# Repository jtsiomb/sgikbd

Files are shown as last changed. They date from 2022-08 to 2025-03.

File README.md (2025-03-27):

SGI - PS/2 keyboard and mouse converter
=======================================

About
-----
This project is a converter for connecting PS/2 keyboards and mice to old
Silicon Graphics computers which had a proprietary keyboard/mouse interface. It
should work on every non-PS/2 SGI computer with mini-DIN6, DB9 and DB15
keyboard/mouse connectors, such as:

  - Iris 4D series
  - Onyx
  - Indigo

This converter is not necessary, and will not work, for any later SGI machines,
like the indy, O2, indigo2, Octane, and so on, because they use PS/2 keyboards
and mice directly.

It's based on an AVR atmega328pb microcontroller, which reads the PS/2
keyboard and mouse ports, and translates scancodes and events to the protocol
and electrical signalling used by the SGI computers. For details on the
SGI signalling and protocols, see the copy of the keyboard and mouse manpages
from the section 7 of the IRIX manual, under `doc/`.

Directory structure:

  - `hw` - hardware: kicad files and pdf schematics.
  - `fw` - firmware for the AVR microcontroller.
  - `case` - 3D printable enclosure for the sgikbd board.
  - `doc` - relevant documentation.

This repository only contains source files. For schematics in PDF format,
zipped gerbers for PCB manufacturing, and human-readable bill of materials, as
well as detailed build instructions, visit the project website:
http://nuclear.mutantstargoat.com/hw/sgikbd

Alternatively download the latest release archive from:
https://github.com/jtsiomb/sgikbd/releases

The firmware is based on my previous
[a500kbd](https://github.com/jtsiomb/a500kbd) project, so if you see any
leftover references to the Amiga anywhere don't be confused.

Note: rev3 of the sgikbd board uses a jumper (J2) to select the negative supply
voltage source. Make sure to **install a jumper there, do not leave it open**.
In most cases the jumper should be placed in the "default" position, but for
some workstations (notably the R3000 indigo) which don't provide a negative
supply on the keyb/mouse port, you might have to move it to the "R3k indigo"
position instead.

For previous revisions of sgikbd, see
[these instructions](http://nuclear.mutantstargoat.com/hw/sgikbd/indigo_r3000_hack.html)
on how to hack it to work with the R3000 indigo.

License
-------
Copyright (C) 2017-2025 John Tsiombikas <nuclear@mutantstargoat.com>

You are free to use, reproduce, modify, and redistribute any part of this
project, provided you make any derivative work you release, freely available
under the same terms.

Both hardware designs, and software parts of this project, are released under
the terms of the GNU General Public License v3, or at your option any later
version published by the Free Software Foundation. See `LICENSE` for details.

To comply with the license, when releasing derivative hardware designs, you must
provide the full EDA project files, and of course firmware/software source code.
Releasing only images of schematics, gerbers, and firmware binaries is *not*
sufficient for compliance.

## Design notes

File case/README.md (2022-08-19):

3D printable case for the sgikbd board
======================================

shot

This case was designed with OpenSCAD. In release archives, this directory
contains STL files exported from OpenSCAD, otherwise if you got this from the
git repository, you will only find the OpenSCAD source file, which you will have
to export yourself. To do so, simply load the `sgikbd.scad` file in OpenSCAD,
press F6 to generate the final geometry for the model, and then press F7 to
export to STL format.

File list
---------
  - `sgikbd.scad`: source file, open it with OpenSCAD to export STL files.
  - `sgikbd-bot.stl`: STL file containing the bottom part of the case in the
    default configuration.
  - `sgikbd-top.stl`: STL file containing the top part of the case in the default
    configuration.
  - `sgikbd-top-allports.stl`: STL file containing the top part of the case, with
    all SGI ports open (no break-away panels).

Options
-------
If you open the source file in openscad and export to STL manually, you can
tweak a number of options about the case. You will find these options at the top
of the file. The default configuration includes break-away panels for all SGI
ports, which you'll have to remove for every connector you have actually
populated on the board. However you have the option to either make any of the
ports completely solid, if you're sure you're not going to populate that
connector in the future, or leave any of the ports completely open.

  - `breaktabs`: set to false to leave ports open, instead of having the default
    break-away panel.
  - `no_db15`: set to true to completely block the DB15 port with solid wall.
  - `no_db9`: set to true to completely block the DB9 port (IRIS 4D series) with
    solid wall.
  - `no-minidin`: set to true to completely block the MiniDIN port (Indigo/Onyx)
    with solid wall.
  - `have_top`: set to false to omit the top part of the case.
  - `have_bottom`: set to false to omit the bottom part of the case.

License
-------
Creator: John Tsiombikas <nuclear@mutantstargoat.com>

This case design is public domain, feel free to copy, modify, and use, as you
will, without restriction.

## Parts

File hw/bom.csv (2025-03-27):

Description | Count | Designator | Footprint | Mouser Part #
22pF capacitor | 2 | C1, C2 | 0805 | 187-CL21C220JBANNNC
0.1uF capacitor | 4 | C3, C6, C7, C9 | 0805 | 187-CL21B104KBFNNNE
0.33uF electrolytic capacitor | 4 | C4, C5, C8, C10 | SMD electrolytic 4.0x5.4 | 647-UWP1HR33MCL
1N4148 diode | 1 | D1 | SOD-123 | 241-1N4148W_R1_00001
AVR programming header | 1 | J1 | 2x3 male pin header 2.54mm pitch (shroud) | 710-61200621621
Jumper pin header | 1 | J2 | 1x3 male pin header 2.54mm pitch | 538-22-28-4035
2N7002 n-channel MOSFET | 1 | Q1 | SOT-23 | 757-T2N7002AKLM
4.7k resistor | 4 | R1, R2, R3, R4 | 0805 | 603-RT0805FRE074K7L
tactile push button | 1 | SW1 | SMD tactile button 6x6mm | 179-TS046670BK160SMT
Atmega328PB microcontroller | 1 | U1 | TQFP-32 | 556-ATMEGA328PB-AU
Mini-DIN 6pin connector | 3 | U2,U3,U5 | Mini-DIN 6pin through-hole | 571-5749180-1
LM358 opamp | 1 | U4 | SOIC-8 | 863-LM358EDR2G
7805 linear voltage regulator | 1 | U6 | SOT-252 | 621-AS7805ADTR-G1
7905 linear voltage regulator | 1 | U7 | SOT-89 | 511-L79L05ABU-TR
DSUB-9 female connector | 1 | U8 | DSUB-9 female through-hole | 649-ID09S33E4GV00LF
DSUB-15 female connector | 1 | U9 | DSUB-15 female through-hole | 649-ID15S33E4GX00LF
Crystal 3.6864MHz | 1 | Y1 | SMD HC49-SD | 815-ABLS-3.6864M-T

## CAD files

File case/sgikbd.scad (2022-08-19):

/* Case for the SGI PS/2 keyboard/mouse converter board
 * by John Tsiombikas <nuclear@mutantstargoat.com>
 *
 * project website: http://nuclear.mutantstargoat.com/hw/sgikbd
 * github repo: https://github.com/jtsiomb/sgikbd
 *
 * This case design is in the public domain, use and modify as you will.
 */

// --------------------- Options ------------------------------
// breaktabs: break-away panels for unpopulated output ports
breaktabs = true;

// no_db15: solid wall where the DB15 port would be
no_db15 = false;
// no_db9: solid wall where the IRIS 4D series DB9 port would be
no_db9 = false;
// no_minidin: solid wall where the Indigo/Onyx mini-din port would be
no_minidin = false;

// include top part of the case
have_top = true;
// include bottom part of the case
have_bottom = true;
// ------------------------------------------------------------


pcb_width = 80;
pcb_height = 60;
pcb_thick = 1.8;
pcb_bev = 4;
holeoffs = 4.5;
hole_d = 3.2;
thick = 1.5;

ps2_h = 13.8;
ps2_w = 14.5;
inp_offs = 20;

db9_w = 32;
db9_h = 14;
db9_offs = 55.2;
db15_w = 40;
db15_h = db9_h;
db15_offs = 50.95;

overhead = db9_h;

stand_h = 3;
stand_d = hole_d * 2;

gap = 0.75;		// total gap between board and case

break_gap = 0.8;


module pcb()
{
	translate([pcb_bev, pcb_bev, -pcb_thick])
	linear_extrude(pcb_thick) {
		minkowski() {
			square([pcb_width-pcb_bev*2, pcb_height-pcb_bev*2]);
			circle(pcb_bev, $fn=40);
		}
	}
}

module ps2port()
{
	translate([-ps2_w/2, -10, 0])
	cube([ps2_w, 20, ps2_h]);
}

module indigoport()
{
	difference() {
		translate([-ps2_w/2, -pcb_width/2+thick*2, 0])
		cube([ps2_w, pcb_width/2, ps2_h]);
		if(breaktabs) {
			translate([-ps2_w/2+break_gap, -thick, 0])
			cube([ps2_w-break_gap*2, thick*3, ps2_h-break_gap]);
			translate([-ps2_w/2-break_gap, 0, ps2_h/2])
			cube([ps2_w+break_gap*2, thick*3, 0.4]);
			
			d = (ps2_w-1-break_gap*2) / 4;
			for(i=[0:d:ps2_w-break_gap*2]) {
				translate([-ps2_w/2+break_gap+i, 0, ps2_h-break_gap-0.5])
				cube([1, thick*3, break_gap+1]);
			}
		}
	}
}

module db9port()
{
	difference() {
		translate([-db9_w/2, -pcb_height/2+thick*2, 0])
		cube([db9_w, pcb_height/2, db9_h]);
		if(breaktabs) {
			translate([-db9_w/2+break_gap, -thick, 0])
			cube([db9_w-break_gap*2, thick*3, db9_h-break_gap]);
			translate([-db9_w/2-break_gap, 0, db9_h/2])
			cube([db9_w+break_gap*2, thick*3, 0.4]);
			
			d = (db9_w-1-break_gap*2) / 10;
			for(i=[0:d:db9_w-2]) {
				translate([-db9_w/2+break_gap+i, 0, db9_h-break_gap-0.5])
				cube([1, thick*3, break_gap+1]);
			}
		}
	}
}

module db15port()
{
	difference() {
		translate([-db15_w/2, -pcb_height/2+thick*2, 0])
		cube([db15_w, pcb_height/2, db15_h]);
		if(breaktabs) {
			translate([-db15_w/2+break_gap, -thick, 0])
			cube([db15_w-break_gap*2, thick*3, db15_h-break_gap]);
			translate([-db15_w/2-break_gap, 0, db15_h/2])
			cube([db15_w+break_gap*2, thick*3, 0.4]);
			
			d = (db15_w-1-break_gap*2) / 13;
			for(i=[0:d:db15_w-2]) {
				translate([-db15_w/2+break_gap+i, 0, db15_h-break_gap-0.5])
				cube([1, thick*3, break_gap+1]);
			}
		}
	}
}

module board()
{
	pcb();
	
	translate([0, inp_offs, 0])
	rotate([0, 0, 90])
	ps2port();
	
	translate([0, pcb_height-inp_offs, 0])
	rotate([0, 0, 90])
	ps2port();
	
	if(!no_minidin) {
		translate([pcb_width, pcb_height/2, 0])
		rotate([0, 0, 270])
		indigoport();
	}
	
	if(!no_db9) {
		translate([db9_offs, pcb_height, 0])
		db9port();
	}
	
	if(!no_db15) {
		translate([db15_offs, 0, 0])
		rotate([0, 0, 180])
		db15port();
	}
}

module case_shape(w, h, bev)
{
	translate([bev, bev, 0])
	minkowski() {
		square([w-bev*2, h-bev*2]);
		circle(bev, $fn=80);
	}
}

module standoff()
{
	cylinder(stand_h, d1=stand_d*1.5, d2=stand_d, $fn=60);
}

module screwhole()
{
	translate([0, 0, -0.5-thick])
	cylinder(stand_h + thick + 1, d=hole_d, $fn=40);
	
	// screw head
	translate([0, 0, -0.1-thick])
	cylinder(3, d=6.8, $fn=50);
	
	translate([0, 0, stand_h])
	cylinder(pcb_thick+overhead-thick, d=2.82, $fn=30);
}

module case_bot()
{
	h = stand_h + thick + pcb_thick;

	difference() {
		union() {
			translate([-thick-gap/2, -thick-gap/2, -h])
			difference() {
				linear_extrude(h)
				case_shape(pcb_width + thick * 2 + gap, pcb_height + thick * 2 + gap, holeoffs);
				
				translate([thick, thick, thick])
				linear_extrude(h)
				case_shape(pcb_width + gap, pcb_height + gap, holeoffs);
			}
			
			for(i=[0:1]) {
				x = holeoffs + i * (pcb_width - holeoffs*2);
				for(j=[0:1]) {
					y = holeoffs + j * (pcb_height - holeoffs*2);
					translate([x, y, -stand_h-pcb_thick])
					standoff();
				}
			}
		}
		for(i=[0:1]) {
			x = holeoffs + i * (pcb_width - holeoffs*2);
			for(j=[0:1]) {
				y = holeoffs + j * (pcb_height - holeoffs*2);
				translate([x, y, -stand_h-pcb_thick])
				screwhole();
			}
		}
	}
}

module case_top()
{
	difference() {
		union() {
			translate([-thick-gap/2, -thick-gap/2, 0])
			difference() {
				linear_extrude(overhead+thick)
				case_shape(pcb_width + thick * 2 + gap, pcb_height + thick * 2 + gap, holeoffs);
			
				translate([thick, thick, -thick])
				linear_extrude(overhead+thick)
				case_shape(pcb_width + gap, pcb_height + gap, holeoffs);
			}
	
			for(i=[0:1]) {
				x = holeoffs + i * (pcb_width - holeoffs*2);
				for(j=[0:1]) {
					y = holeoffs + j * (pcb_height - holeoffs*2);
					translate([x, y, 0.25])	// tolerance for pcb thickness
					cylinder(overhead, d1=stand_d * 0.9, d2=stand_d * 1.8, $fn=40);
				}
			}
		}
		
		translate([0, 0, -0.01])
		board();
		
		for(i=[0:1]) {
			x = holeoffs + i * (pcb_width - holeoffs*2);
			for(j=[0:1]) {
				y = holeoffs + j * (pcb_height - holeoffs*2);
				translate([x, y, -stand_h-pcb_thick])
				screwhole();
			}
		}
	}
}

if(have_bottom) {
	translate([0, 5, stand_h+thick+pcb_thick])
	case_bot();
}


if(have_top) {
	translate([0, -5, overhead+thick])
	rotate([180, 0, 0])
	case_top();
}

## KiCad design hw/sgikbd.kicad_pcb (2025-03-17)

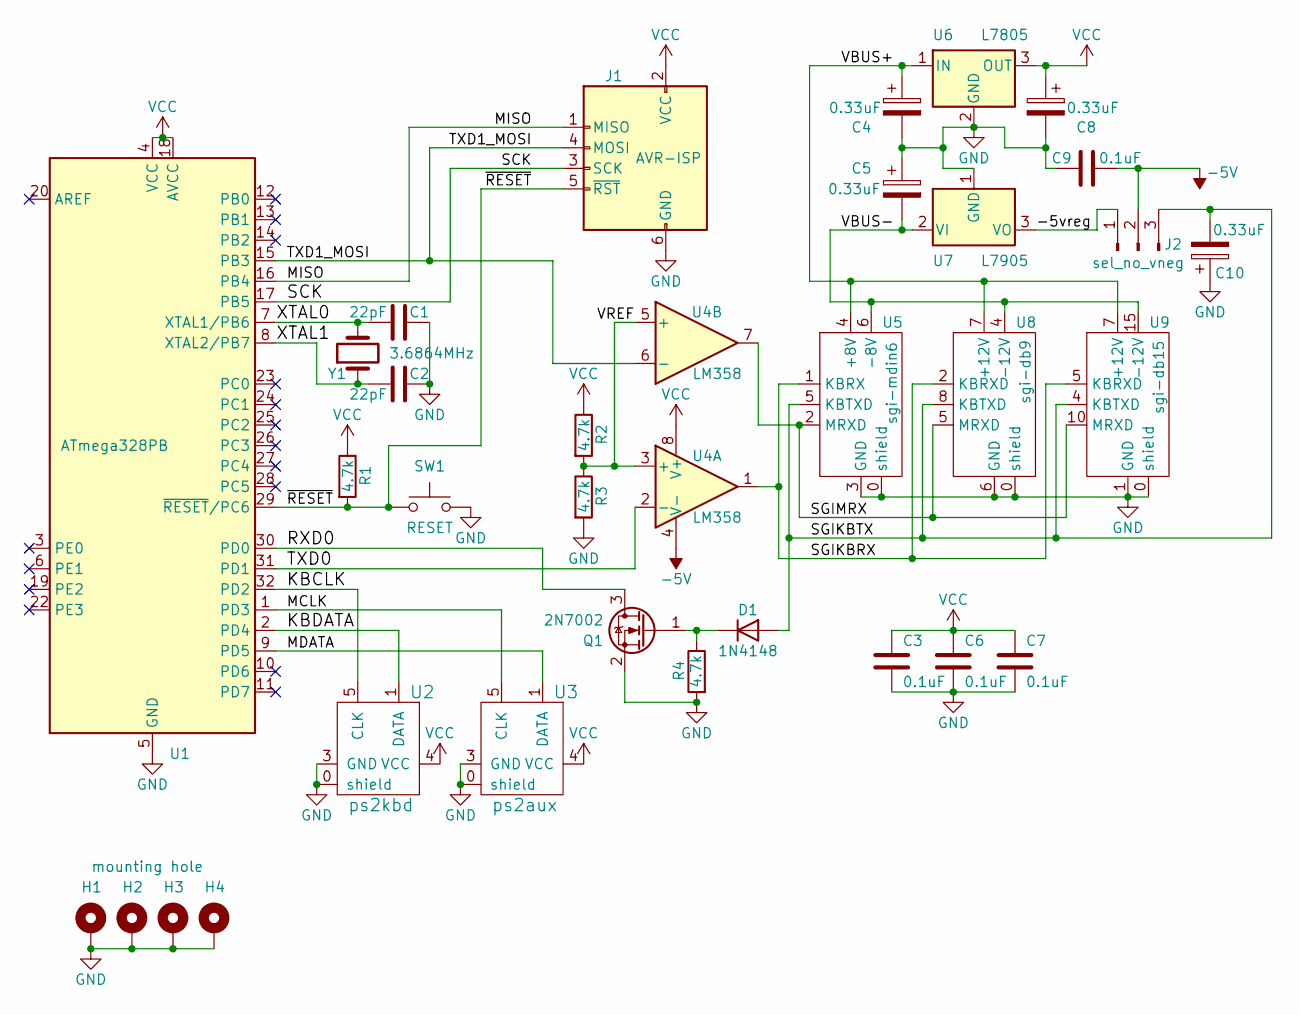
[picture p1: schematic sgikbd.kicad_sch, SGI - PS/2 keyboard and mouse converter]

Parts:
C1, C2: 22pF; C_0805_2012Metric_Pad1.18x1.45mm_HandSolder
C3, C6, C7, C9: 0.1uF; C_0805_2012Metric_Pad1.18x1.45mm_HandSolder
C4, C5, C8, C10: 0.33uF; CP_Elec_4x5.4
D1: 1N4148; D_SOD-123
H1, H2, H3, H4: mounting hole; MountingHole_3.2mm_M3_Pad
J1: AVR-ISP; IDC-Header_2x03_P2.54mm_Vertical
J2: sel_no_vneg; PinHeader_1x03_P2.54mm_Vertical
Q1: 2N7002; SOT-23
R1, R2, R3, R4: 4.7k; R_0805_2012Metric_Pad1.20x1.40mm_HandSolder
SW1: RESET; SW_Push_1P1T_NO_6x6mm_H9.5mm
U1: ATmega328PB; TQFP-32_7x7mm_P0.8mm
U2: ps2kbd; minidin6
U3: ps2aux; minidin6
U4: LM358; SOIC-8_3.9x4.9mm_P1.27mm
U5: sgi-mdin6; minidin6
U6: L7805; TO-252-3_TabPin2
U7: L7905; SOT-89-3_Handsoldering
U8: sgi-db9; DSUB-9_Female_Horizontal_P2.77x2.84mm_EdgePinOffset7.70mm_H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
U9: sgi-db15; DSUB-15_Female_Horizontal_P2.77x2.84mm_EdgePinOffset7.70mm_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
Y1: 3.6864MHz; Crystal_SMD_HC49-SD

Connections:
-5V: C9.2, J2.2, U4.4 (V-)
/-5vreg: J2.1, U7.3 (VO)
/KBCLK: U1.32 (PD2), U2.5 (CLK)
/KBDATA: U1.2 (PD4), U2.1 (DATA)
/MCLK: U1.1 (PD3), U3.5 (CLK)
/MDATA: U1.9 (PD5), U3.1 (DATA)
/MISO: J1.1 (MISO), U1.16 (PB4)
/RXD0: Q1.3 (D), U1.30 (PD0)
/SCK: J1.3 (SCK), U1.17 (PB5)
/SGIKBRX: U4.1, U5.1 (KBRX), U8.2 (KBRXD), U9.5 (KBRXD)
/SGIKBTX: C10.2, D1.2 (A), J2.3, U5.5 (KBTXD), U8.8 (KBTXD), U9.4 (KBTXD)
/SGIMRX: U4.7, U5.2 (MRXD), U8.5 (MRXD), U9.10 (MRXD)
/TXD0: U1.31 (PD1), U4.2 (-)
/TXD1_MOSI: J1.4 (MOSI), U1.15 (PB3), U4.6 (-)
/VBUS+: C4.1, U5.4 (+8V), U6.1 (IN), U8.7 (+12V), U9.7 (+12V), U9.8 (+12V), U9.9 (+12V)
/VBUS-: C5.2, U5.6 (-8V), U7.2 (VI), U8.4 (-12V), U9.15 (-12V)
/VREF: R2.2, R3.1, U4.3 (+), U4.5 (+)
/XTAL0: C1.1, U1.7 (XTAL1/PB6), Y1.2
/XTAL1: C2.1, U1.8 (XTAL2/PB7), Y1.1
/~RESET: J1.5 (~RST), R1.2, SW1.1, U1.29 (~RESET/PC6)
GND: C1.2, C2.2, C3.2, C4.2, C5.1, C6.2, C7.2, C8.2, C9.1, C10.1, H1.1, H2.1, H3.1, H4.1, J1.6 (GND), Q1.2 (S), R3.2, R4.2, SW1.2, U1.5 (GND), U1.21 (GND), U2.0 (shield), U2.3 (GND), U3.0 (shield), U3.3 (GND), U5.0 (shield), U5.3 (GND), U6.2 (GND), U7.1 (GND), U8.0 (shield), U8.6 (GND), U8.9 (GND), U9.0 (shield), U9.1 (GND), U9.2 (GND), U9.3 (GND)
unnamed: D1.1 (K), Q1.1 (G), R4.1
VCC: C3.1, C6.1, C7.1, C8.1, J1.2 (VCC), R1.1, R2.1, U1.4 (VCC), U1.18 (AVCC), U2.4 (VCC), U3.4 (VCC), U4.8 (V+), U6.3 (OUT)

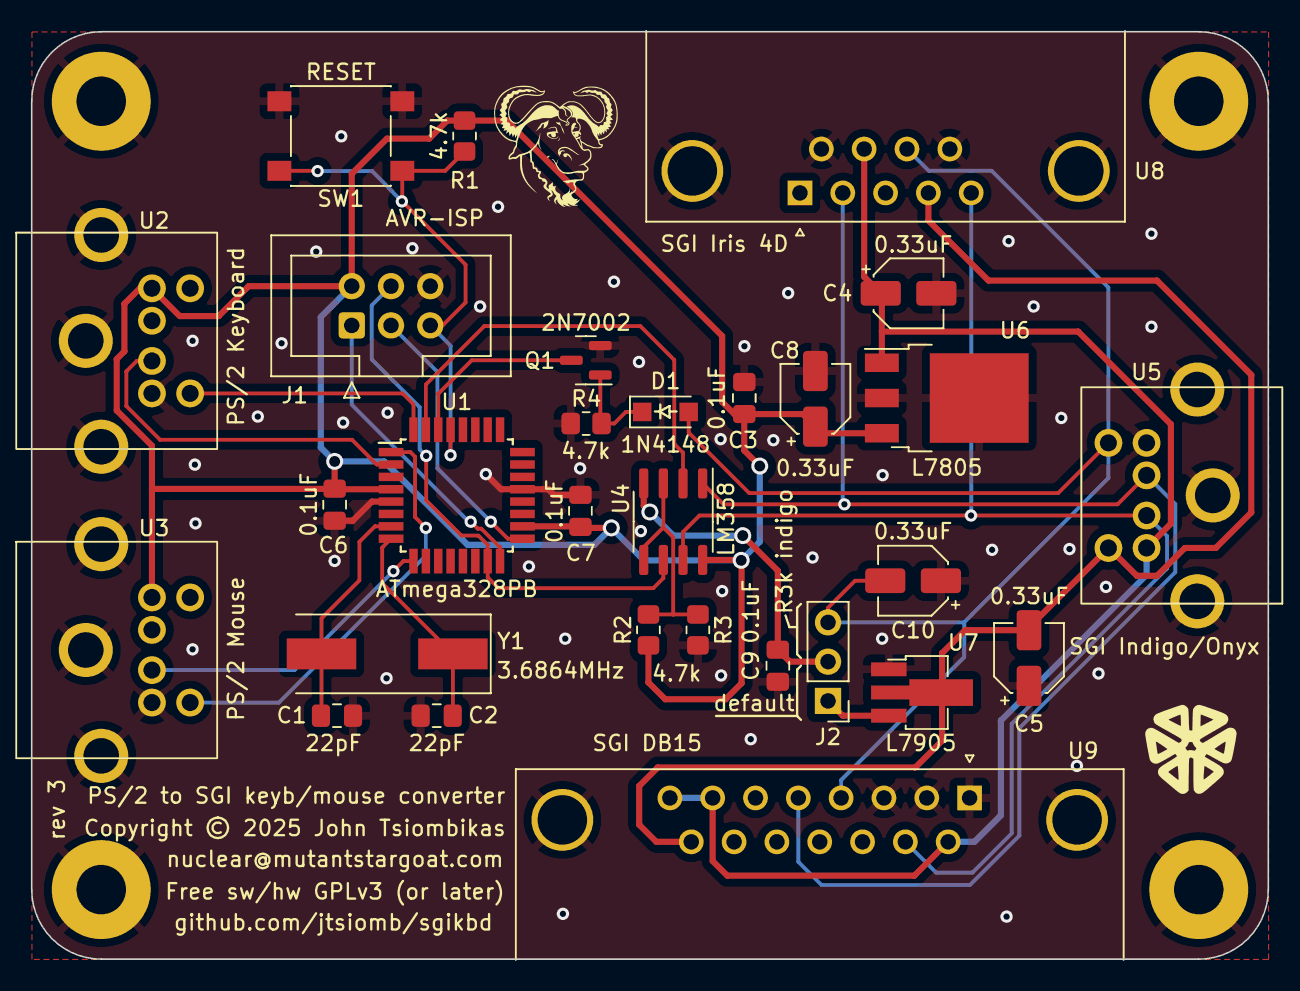
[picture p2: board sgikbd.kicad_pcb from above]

Board: 2 copper layers, 80.0 x 60.0 mm, 33 parts (0 on the bottom side), 23 nets.

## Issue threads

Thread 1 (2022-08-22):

Middle-click doesn't work for microsoft wheel-mice

jtsiomb, 2022-08-22:
Microsoft wheel-mice apparently do not transmit any change packets in streaming mode by default when the middle button changes state.

Potential ways to fix the issue:
  - Switch the mouse into their native ImPS2 protocol with 4-byte packets and see if that makes a difference.
  - Abandon streaming mode, and continuously poll the mouse for changes.

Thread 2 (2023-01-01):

Reported lack of -8V DC on an R3000 indigo

jtsiomb, 2023-01-01:
I got a report via email of at least one Indigo R3000 which lacks the -8V DC power rail on pin 6 of the mini-DIN keyboard/mouse port (see doc/sgi_man7_keyboard). This board will not work without it. We need to figure out how many machines are affected by this.

A hack to overcome this problem would be to make a cable to grab -12V from an unused serial port, and connect it to one of the pins marked "V-" on the back side of the sgikbd board, on one of the D-SUB connectors (not the mini-din). Then remove pin 6 of the mini-din connector, to avoid back-feeding the computer through it, or cut the two traces going to pin 6 of the mini-din on the top side of the board.

jtsiomb, 2024-06-23:
The way to overcome this problem by modifying the sgikbd board is documented here: http://nuclear.mutantstargoat.com/hw/sgikbd/indigo_r3000_hack.html

Not closing this issue until I redesign sgikbd to integrate the hack.

jtsiomb, 2025-03-27:
rev3 of the board (sgikbd release 1.2) has the r3k indigo hack integrated, and selectable by jumper (J2).

Closed 2025-03-27.

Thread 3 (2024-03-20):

Some PS/2 mice don't work

julianfnunez, 2024-03-20:
Creating this here to track this issue.

My PS/2 mouse doesn't seem to be working. Here's what I've checked so far.

- Mouse works in another machine. Keyboard works fine when connected to Indigo through adapter.
- I see activity on mouse DATA and CLOCK when connected to adapter, only while moving it. (Oscilloscope)
- No activity on pin 6 of LM358 (Oscilloscope).
- Good continuity between PS/2 port DATA and pin 9 on the mega.
- Good continuity between mega pin 15 and LM358 pin 6.

I will do more testing tonight seeing voltage levels on the DATA and CLOCK pins of the ps/2 mouse connector.

jtsiomb, 2024-03-20:
Thanks for the bug report, please let me know what you find if/when you get to trace this further. I'll try to find some time for debugging myself, but you'll probably beat me to it.

julianfnunez, 2024-03-22:
Had a chance to test it.

Both DATA and CLOCK, at idle 5.04 volts. While moving the mouse seems like they go up to 5.12v, also VPP 5.24 volts (peak to peak) while moving the mouse. Is that what you need?

jtsiomb, 2024-03-22:
That's not right at all. It should send a series of pulses between 0 and 5 volts. Did you measure that with a scope?

Did you try any other mice?

julianfnunez, 2024-03-22:
Hey, sorry man, didn't express myself correctly. Yes, I do see square wave pulses when I move my mouse, the behavior is:

- Constant 5.04v when I don't move the mouse in CLOCK and DATA.
- Square wave pulses between 5.12v and 0 volts when I move the mouse, both in DATA and CLOCL. During these pulses the peak-to-peak shows as 5.24 volts.

jtsiomb, 2024-03-25:
I did a little bit of testing of the adaptor standalone (not connected to the indigo, because it's a big hassle to pull it out and set it up right now). Gave it power connected various mice, and probed the input and output sides of the microcontroller. Every mouse I tried which sent data in, caused the microcontroller to send data out as well.

The only failure was that logitech mouse, but also it wasn't sending anything at all, so I don't know what's wrong with it. Maybe it's a USB-only mouse.

julianfnunez, 2024-03-26:
Ok, thanks for checking! I will build another one from scratch and test that. Will be a bit of time though as I'm going to be away for about 2 weeks.

jtsiomb, 2024-03-26:
Now that I think about it some more, aside from the logitech mouse which never worked, I think the fault I had with some of the other mice I mentioned above was not that they weren't working at all, but that the middle mouse button was not doing anything. That was the bug I encountered and never got around to debug and fix...

Sorry for misleading you, it's been a while and I forgot the details. Apparently I even added an issue about this 2 and a half years ago (issue #1), and entirely forgot about it...

julianfnunez, 2024-04-29:
Hello John!

I appreciate your messages so much. Thank you! I am finally back in the country and had a chance to play with this again. I ended up building another one just to see if the issue was with the way I assembled it. Unfortunately, the exact problem happens with the second one! Keyboard works great but no mouse activity. I hooked up my oscilloscope to the ATmega pins and took some pictures of what I see while I move the mouse.

This is what I see in the ATmega pin 1:
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

And this is in pin 9:

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

Pin 15 stays high all the time. Just constant 5v.

Also here's a picture of my assembled adapter just in case:

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

jtsiomb, 2024-04-29:
Is there any chance you used an ATmega328P instead of the ATmega328PB? I can't see the markings in the photo.

julianfnunez, 2024-04-29:
Yes! It seems to be the MEGA328PB-U by the markings. The bag matches the Mouser partnumber in your BOM file: 556-ATMEGA328PB-AU

jtsiomb, 2024-04-29:
Alright, I asked because the 328p lacks the second UART, it has only one. And the second UART is the one used to send mouse input to the computer. Also because if I'm not mistaken, I think the idle state of the UART is low, not high, so I would expect if nothing is happening it should read 0 on pin15. While if it was a 328p pin 15 is just an I/O pin and it would make sense to be pulled high with the internal pullups.

But as you said, it would raise errors during programming if the device didn't match.

The next thing I would try, is to toggle some pins when packets are received by the microcontroller, to see what's going on. The two lowest pins of port C are already declared as outputs for debugging purposes, so I would probably go to `ps2.c` in `ISR(INT1_vect)` and do something like `PORTC ^= 1;` somewhere to have the first bit (pin 23) toggle every time there's an interrupt,
and then go into `psaux_read` after the `while` and do `PORTC ^= 2;` to have the second bit (pin 24) toggle every time a full packet is received correctly.

jtsiomb, 2024-04-29:
Also, which exact mice have you tested? Maybe I have or can find one to try and reproduce the problem.

julianfnunez, 2024-04-29:
That sounds great, I'll give that a try!

My mouse is a Logitech M-S69.

julianfnunez, 2024-04-30:
Alright, we have some results. After some issues compiling this with newer versions of the tools, finally got it to compile and run again. After the modifications you suggested I do see activity on pin 23, but pin 24 is quiet, no activity whatsoever.

julianfnunez, 2024-04-30:
So it seems to me this condition is never true in psaux_pending()

mpkt_rd != mpkt_wr;

Next thing I will do is move those PORTC bit flipping into the different switch/cases in the ISR(INT1_vect) handler. I want to know what's going on in that function that's causing the mpkt_wr not to advance.

julianfnunez, 2024-05-01:
Hi John! I'm happy to report that after some tedious moving of the PORTC bit flipping line in different parts of the code, I was able to make it work with my mouse!

It ended up being because in this block:
```
			case 2:		/* expect ACK after enable data reporting command */
				if(value == PS2_ACK) {
					auxstate = 0xff;
				} else {
					auxstate = 0;
				}
				break;
```
It never goes into the PS2_ACK condition here, so auxstate is never 0xff. I ended up commenting out this: auxstate = 0; so even when value is different than PS2_ACK, it will not restart the whole thing. After doing that, it started working!

My guess is this mouse is sending something extra that's not PS2_ACK for some reason. Or the initialization for this particular model might require more elaborate steps? I'm really not familiar with any of this... what do you think?

jtsiomb, 2024-05-01:
hmmm that's interesting. In theory the mouse should respond to any commands we send it with an ACK. It would probably be a good idea to add timeouts instead of blocking waiting for the ACK indefinitely.

julianfnunez, 2024-05-01:
You're right, with my change we're now waiting for the ACK forever... I'll see if I can add that timeout and set the auxstate back to 0 if we hit it.

I would love to somehow see the value of the 'value' variable to see what the mouse is sending back.

jtsiomb, 2024-05-01:
No, now that I look at the code again, you're right, it looks like your mouse just sends something else before the ACK, but the code expecting an ACK there resets the whole process and waits for 0xaa again, which will never happen. So by removing the auxstate = 0 part, you're just ignoring whatever the mouse sent and keep waiting for the ACK, which eventually arrives. Resetting auxstate back to 0, without also transmitting a reset command doesn't make sense at all, it's doom to hang forever.

I think as a first stopgap what you did is fine. The timeout I was thinking about earlier was the opposite, to just bail out of that whole state machine and try to accept packets from the mouse if they arrive after some timeout. So basically pretend like ACK came by setting auxstate = 0xff after some time. That's not ideal either, but has a chance to salvage the situation if something weird happens.

But don't worry about it for now. I'll probably have to rewrite this whole process to make it more robust at some point, and possibly also fix the mousewheel issue on other mice. But I need to find time for experimentation, and ideally also get a signal analyzer. It's hard to keep track of a whole communication sequence with just an oscilloscope.

julianfnunez, 2024-05-01:
Sounds good John, thanks for all your guidance on this.

Also, while I was messing with this, I found this page which has some captures of mouse interactions with standard AT bioses. These look pretty involved: https://isdaman.com/alsos/hardware/mouse/ps2interface.htm

Next step is to try that ps2 to usb adapter and see if this also fixes that. I also wonder if after this change your mice would work also? I assume yes since the ACK seems to arrive right away for your models.

julianfnunez, 2024-05-03:
I tried the PS2 to USB adapter and that still doesn't work, but there's something else going on there... The laser mouse is not even turning the laser on, like it was not connected at all, and there's no activity even on the input pins, so that's for another investigation. I'll spend some time with the Indigo now that I can use it. Thanks again for all your help and for creating this!

Closed 2024-05-03.

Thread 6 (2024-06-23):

Issue relating to power cycling and PS/2 mice

Wert688, 2024-06-23:
Quickly turning an R4k Indigo (R3k untested) on and off results in the mouse's inputs no longer being recognized when the system comes back up. The keyboard will continue to work, and the issue can be fixed temporarily by unplugging and plugging the adapter back in after the system is powered down. Longer power cycles (e.g. overnight) seem to not have this issue.

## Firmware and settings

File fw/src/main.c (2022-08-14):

#include <stdio.h>
#include <ctype.h>
#include <avr/io.h>
#include <avr/interrupt.h>
#include <util/delay.h>
#include "serial.h"
#include "scantbl.h"
#include "ps2.h"
#include "sgi.h"
#include "defs.h"
#include "timer.h"

enum {
	KF_BRK = 1,
	KF_EXT = 2,
	KF_EXT1 = 4,
};

void proc_atkbd(void);
void proc_psaux(void);

int main(void)
{
	unsigned char prevled, led;

	DDRB = 0;
	DDRC = 3;	/* debug out */
	DDRD = 0;
	DDRE = 0;
	PORTB = 0xff;
	PORTC = 0xfc;
	PORTD = 0xff;	/* pull-ups on PS/2 ports, pull-up on RX0 */
	PORTE = 0xff;
	EIMSK = 0;	/* mask external interrupts */
	EICRA = (1 << ISC11) | (1 << ISC01);	/* falling edge interrupts */

	init_timer();

	/* initialize the UART and enable interrupts */
	init_serial(0, 600, 8, PAR_ODD, 1);		/* SGI keyboard */
	init_serial(1, 4800, 8, PAR_NONE, 1);	/* SGI mouse */
	sei();

	EIMSK = (1 << INT0) | (1 << INT1);	/* enable ps/2 clock interrupts */

	ps2kb_setled(0);	/* start with all LEDs off */
	prevled = 0;

	for(;;) {
		sgi_procinp();

		led = ((sgi_ledstate & 3) << 1) | ((sgi_ledstate & 4) >> 2);
		if(led != prevled) {
			ps2kb_setled(led);
			prevled = led;
		}

		proc_atkbd();
		proc_psaux();
	}
	return 0;
}

void proc_atkbd(void)
{
	static unsigned int keyflags;
	static unsigned char prev_e0;
	unsigned char c, keycode;
	int press;

	if(!ps2kb_pending()) return;

	c = ps2kb_read();
	switch(c) {
	case 0xe0:	/* extended */
		keyflags |= KF_EXT;
		break;

	case 0xe1:	/* extended */
		keyflags |= KF_EXT1;
		break;

	case 0xf0:	/* break code */
		keyflags |= KF_BRK;
		break;

	default:
		keycode = 0xff;
		if(keyflags & KF_EXT) {
			if((c == 0x12 && prev_e0 == 0x7c) || (c == 0x7c && prev_e0 == 0x12)) {
				keycode = 0x62;	/* print screen */
				prev_e0 = 0;
			} else {
				prev_e0 = c;
				if(c < KEYMAP_EXT_SIZE) {
					keycode = keymap_ext[(int)c];
				}
			}
		} else if(keyflags & KF_EXT1) {
			prev_e0 = 0;
		} else {
			if(c < KEYMAP_NORMAL_SIZE) {
				keycode = keymap_normal[(int)c];
			}
			prev_e0 = 0;
		}

		if(keycode != 0xff) {
			press = ~keyflags & KF_BRK;
			sgi_sendkey(keycode, press);
		}
		keyflags = 0;
	}
}

void proc_psaux(void)
{
	struct mouse_input inp;

	if(!psaux_pending()) return;

	psaux_read(&inp);

	sgi_sendmouse(inp.bnstate, inp.dx, inp.dy);
}

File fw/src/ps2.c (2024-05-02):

#include <avr/io.h>
#include <avr/interrupt.h>
#include <util/delay.h>
#include "ps2.h"
#include "defs.h"
#include "timer.h"

#define TIMEOUT	100

#define BUF_SZ	32
#define BUF_IDX_MASK	(BUF_SZ - 1)
#define NEXT_IDX(x) (((x) + 1) & BUF_IDX_MASK)
static volatile unsigned char keybuf[BUF_SZ];
static volatile unsigned char key_rd, key_wr;

struct mpkt {
	unsigned char data[3];
};
static volatile struct mpkt mpktbuf[BUF_SZ];
static volatile unsigned char mpkt_rd, mpkt_wr;

static volatile struct mpkt curpkt;
static volatile unsigned char curpkt_byte;
static volatile int auxstate;

static volatile int send_nbits, wait_ack;
static volatile unsigned char send_val, send_par;

static int ps2write(unsigned char c, unsigned char ckbit, unsigned char dbit);
static void abort_send(unsigned char ckbit, unsigned char dbit);

int ps2kb_write(unsigned char c)
{
	return ps2write(c, KCLK_BIT, KDATA_BIT);
}

static int ps2write(unsigned char c, unsigned char ckbit, unsigned char dbit)
{
	cli();
	send_nbits = 10;
	send_val = c;
	send_par = 0;	/* init to 0, will be calculated while sending */

	/* inhibit transmission, hold at least 100us */
	PORTD &= ~ckbit;
	DDRD |= ckbit;
	EIFR |= (1 << INTF0);	/* clear pending interrupt due to clock transition */
	sei();
	_delay_us(100);

	/* RTS by data low & release clock (this counts as start bit?) */
	PORTD &= ~dbit;
	DDRD |= dbit;
	DDRD &= ~ckbit;

	reset_timer();
	while(send_nbits > 0) {
		if(get_msec() > TIMEOUT) {
			abort_send(ckbit, dbit);
			return -1;
		}
	}
	_delay_us(5);

	/* release data line and wait for ack */
	cli();
	wait_ack = 1;
	sei();
	DDRD &= ~dbit;
	reset_timer();
	while(wait_ack) {
		if(get_msec() > TIMEOUT) {
			abort_send(ckbit, dbit);
			return -1;
		}
	}
	return 0;
}

static void abort_send(unsigned char ckbit, unsigned char dbit)
{
	cli();
	send_nbits = 0;
	wait_ack = 0;
	/* hold clock low for 100us */
	PORTD &= ~ckbit;
	DDRD |= ckbit;
	_delay_us(100);
	DDRD &= ~(ckbit | dbit);
	if(ckbit == KCLK_BIT) {
		EIFR |= (1 << INTF0);	/* clear pending interrupt */
	} else {
		EIFR |= (1 << INTF1);
	}
	sei();
}

unsigned char ps2kb_read(void)
{
	unsigned char key;

	while(key_rd == key_wr) {
	}

	cli();
	key = keybuf[key_rd];
	key_rd = NEXT_IDX(key_rd);
	sei();

	return key;
}

int ps2kb_pending(void)
{
	return key_rd != key_wr;
}


int ps2kb_wait(unsigned int timeout)
{
	reset_timer();
	while(key_rd == key_wr) {
		if(get_msec() >= timeout) return -1;
	}
	return 0;
}

void ps2kb_clearbuf(void)
{
	key_rd = key_wr;
}

int psaux_write(unsigned char c)
{
	return ps2write(c, MCLK_BIT, MDATA_BIT);
}

void psaux_read(struct mouse_input *inp)
{
	unsigned char pkt[3];
	while(mpkt_rd == mpkt_wr);

	cli();
	pkt[0] = mpktbuf[mpkt_rd].data[0];
	pkt[1] = mpktbuf[mpkt_rd].data[1];
	pkt[2] = mpktbuf[mpkt_rd].data[2];
	mpkt_rd = NEXT_IDX(mpkt_rd);
	sei();

	inp->bnstate = pkt[0] & 7;
	inp->dx = (short)pkt[1] - (((short)pkt[0] << 4) & 0x100);
	inp->dy = (short)pkt[2] - (((short)pkt[0] << 3) & 0x100);
}

int psaux_pending(void)
{
	return mpkt_rd != mpkt_wr;
}

#define PS2_ACK		0xfa
#define PS2_RESEND	0xfe
#define PS2_ECHO	0xee

int ps2kb_setled(unsigned char state)
{
	unsigned char c;

	ps2kb_write(0xed);
	reset_timer();
	while(!ps2kb_pending()) {
		if(get_msec() >= TIMEOUT) return -1;
	}
	c = ps2kb_read();
	/*printf("ps2setled 1st response: %x\r\n", (unsigned int)c);*/
	if(c != PS2_ACK) return -1;

	ps2kb_write(state);
	reset_timer();
	while(!ps2kb_pending()) {
		if(get_msec() >= TIMEOUT) return -1;
	}
	c = ps2kb_read();
	/*printf("ps2setled 2nd response: %x\r\n", (unsigned int)c);*/
	if(c != PS2_ACK) return -1;

	return 0;
}

ISR(INT0_vect)
{
	static unsigned char value, parity;
	/*static unsigned char valp;*/
	static int nbits;

	if(wait_ack) {
		if(!(PIND & KDATA_BIT)) {
			wait_ack = 0;
		}
		return;
	}

	if(send_nbits > 0) {
		--send_nbits;
		switch(send_nbits) {
		case 1:		/* parity bit */
			if(send_par & 1) {	/* odd number of ones: parity 0 */
				PORTD &= ~KDATA_BIT;
			} else {	/* even number of ones: parity 1 */
				PORTD |= KDATA_BIT;
			}
			break;
		case 0:	/* stop bit: 1 */
			PORTD |= KDATA_BIT;
			break;
		default:
			if(send_val & 1) {
				PORTD |= KDATA_BIT;
				++send_par;
			} else {
				PORTD &= ~KDATA_BIT;
			}
			send_val >>= 1;
		}

	} else {
		if(nbits > 0 && nbits < 9) {
			value >>= 1;
			if(PIND & KDATA_BIT) {
				value |= 0x80;
				parity ^= 1;
			}
		}/* else if(nbits == 9) {
			valp = (PIND >> KDATA) & 1;
		}*/
		if(++nbits >= 11) {
			nbits = 0;

			/* check parity */
			/*if((parity & 1) == (valp & 1)) {}*/
			keybuf[key_wr] = (unsigned char)value;
			key_wr = NEXT_IDX(key_wr);

			value = 0;
			parity = 0;
		}
	}
}

ISR(INT1_vect)
{
	static unsigned char value, parity;
	static int nbits;

	if(wait_ack) {
		if(!(PIND & MDATA_BIT)) {
			wait_ack = 0;
		}
		return;
	}

	if(send_nbits > 0) {
		--send_nbits;
		switch(send_nbits) {
		case 1:		/* parity bit */
			if(send_par & 1) {	/* odd number of ones: parity 0 */
				PORTD &= ~MDATA_BIT;
			} else {	/* even number of ones: parity 1 */
				PORTD |= MDATA_BIT;
			}
			break;
		case 0:	/* stop bit: 1 */
			PORTD |= MDATA_BIT;
			break;
		default:
			if(send_val & 1) {
				PORTD |= MDATA_BIT;
				++send_par;
			} else {
				PORTD &= ~MDATA_BIT;
			}
			send_val >>= 1;
		}

	} else {
		if(nbits > 0 && nbits < 9) {
			value >>= 1;
			if(PIND & MDATA_BIT) {
				value |= 0x80;
				parity ^= 1;
			}
		}/* else if(nbits == 9) {
			valp = (PIND >> MDATA) & 1;
		}*/
		if(++nbits >= 11) {
			nbits = 0;

			/* check parity */
			/*if((parity & 1) == (valp & 1)) {}*/

			switch(auxstate) {
			case 0:		/* not initialized */
				if(value == 0xaa) {
					auxstate++;
				}
				break;

			case 1:		/* expect ID after BAT */
				if(value == 0) {
					auxstate++;
					/* enable data reporting */
					ps2write(0xf4, MCLK_BIT, MDATA_BIT);
				} else {
					auxstate = 0;
				}
				break;

			case 2:		/* expect ACK after enable data reporting command, ignore anything else until we get it */
				if(value == PS2_ACK) {
					auxstate = 0xff;
				} 
				break;

			default:
				curpkt.data[curpkt_byte++] = (unsigned char)value;
				if(curpkt_byte >= 3) {
					mpktbuf[mpkt_wr].data[0] = curpkt.data[0];
					mpktbuf[mpkt_wr].data[1] = curpkt.data[1];
					mpktbuf[mpkt_wr].data[2] = curpkt.data[2];
					mpkt_wr = NEXT_IDX(mpkt_wr);
					curpkt_byte = 0;
				}
			}

			value = 0;
			parity = 0;
		}
	}
}

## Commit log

2022-06-30 sgikbd initial commit (based on a500kbd: https://github.com/jtsiomb/a500kbd)
    [sgikbd.sch]
2022-07-03 migrated the kicad project
    [sgikbd.kicad_sch]
2022-07-17 schematic progress
    [sgikbd.kicad_sch]
2022-07-18 first board revision completed
    [sgikbd.kicad_sch]
2022-07-20 PCB design done + bom and readme
    [bom.csv, sgikbd.kicad_pcb]
2022-07-31 - add pull-up to the serial RX pin to go with the transistor inverter bodge - forgot to reset keyflags after processing an extended or break scancode
    [main.c]
2022-07-31 fixed UART polarity
    [sgikbd.kicad_pcb, sgikbd.kicad_sch]
2022-08-03 first mouse test unsuccessfull, broke keyboard too
    [main.c, ps2.c, sgi.c]
2022-08-05 minor schematic cleanup
    [sgikbd.kicad_sch]
2022-08-09 handle LEDs
2022-08-09 fixed mistranslation of the scancode for the quote key
    [main.c, sgi.c]
2022-08-10 update BOM
    [bom.csv]
2022-08-14 detect printscr, and fixed mapping of numpad 8
    [main.c, sgi.c]
2022-08-19 added 3d printed case
    [sgikbd.scad]
2022-08-19 case readme
2024-05-01 Ignore other values while waiting for mouse ACK
    Some mice seem to send other values before we get the ACK. This was causing auxstate to be reset and the code was back to auxstate=0, waiting for 0xAA which will never happen.
    This change is to ignore other values and stay in auxstate=2 indefinitely until we get the ACK, which eventually comes.
    This makes the Logitech M-S69 mouse work (and possibly others).
    [ps2.c]
2024-06-23 updated kicad files for kicad 8.0
    [sgikbd.kicad_pcb, sgikbd.kicad_sch]
2025-03-17 rev3: jumper-selectable R3K hack
    [sgikbd.kicad_pcb, sgikbd.kicad_sch]
2025-03-27 update bom for rev3
    [bom.csv]

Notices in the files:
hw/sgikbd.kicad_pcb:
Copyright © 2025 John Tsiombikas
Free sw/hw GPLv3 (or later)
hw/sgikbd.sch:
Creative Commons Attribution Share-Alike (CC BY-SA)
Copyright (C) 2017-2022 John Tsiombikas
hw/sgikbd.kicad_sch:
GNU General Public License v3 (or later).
